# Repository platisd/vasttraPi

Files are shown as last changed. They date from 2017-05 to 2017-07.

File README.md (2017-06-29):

# VasttraPi
Your personal departures screen for Västtrafik buses. Currently it is hardcoded to look for buses going from Lindholmen to the center, but can be easily modified or extended. It uses a Python wrapper ([PyTrafik](https://github.com/axelniklasson/PyTrafik)), around the Västtrafik API by Axel Niklasson. Read more about the project and its background [here](https://platis.solutions/blog/2017/06/18/vasttrapi-my-personalized-vasttrafik-bus-stop/).

vasttrapi photo

## How to install
First, prepare your Raspberry Pi for connecting with your local wireless network and enable SSH. The following guide has been tested on **2017-03-02-raspbian-jessie** running on a **Raspberry Pi Zero W**.

* Set the correct timezone to your Pi
  * `sudo raspi-config`
  * Localisation Options
  * Change timezone
  * Europe
  * Stockholm
* Clone the vasttraPi repository
  * `git clone https://github.com/platisd/vasttraPi.git`
* Clone the PyTrafik repository
  * `git clone https://github.com/axelniklasson/PyTrafik.git`
* Install the PyTrafik Python3 module
  * `sudo pip3 install PyTrafik/`
* Make sure you have PySerial 3.3 or greater installed
  * sudo pip3 install pyserial --upgrade
* Create an api-config file with your [Västtrafik API tokens](https://developer.vasttrafik.se/portal/#/applications)
  * `nano vasttraPi/api-config`
  * Add your API tokens. The first line should be the (public) key and the second is the secret.
api config screenshot
* Make the Python3 GUI start right after boot
  * `nano /home/pi/.xsession`
  * Add: `python3 /home/pi/vasttraPi/departures.py`
  * To undo this, do not just empty the .xsession file, remove it completely.
* Sync, reboot and the departures screen should pop up
  * `sync`
  * `sudo reboot`

### Read-only & OverlayFS (Optional)
The Python3 script, which is configured to run on startup, is listening to the serial port for an "off" string in order to shutdown the Raspberry Pi. This is done in order to protect the SD card from being corrupted, even though this has rarely happened to me. That being said, if you do not want to bother with the extra USB-serial connection or feel like trying something new, an effective way of protecting the SD card is by using a read-only filesystem and OverlayFS. After a lot of search I found the great [instructions](http://wiki.psuter.ch/doku.php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) by Pascal Suter who provided a very useful [script](overlayRoot.sh) in order to achieve that.

* Copy the `overlayRoot.sh` script to `/sbin/`
  * `sudo cp /home/pi/vasttraPi/overlayRoot.sh /sbin/`
* Disable swap
  * `sudo dphys-swapfile swapoff`
  * `sudo dphys-swapfile uninstall`
  * `sudo update-rc.d dphys-swapfile remove`
* Once you have your partitions set up the way you want them edit the `/boot/cmdline.txt` to run the `overlayRoot.sh` script.
  * `nano /boot/cmdline.txt`
  * Append `init=/sbin/overlayRoot.sh` to the end of the existing file.
* After rebooting, any changes to the partitions will be non-persistent. If you want to undo this, simply restore the `/boot/cmdline.txt` to its original state.

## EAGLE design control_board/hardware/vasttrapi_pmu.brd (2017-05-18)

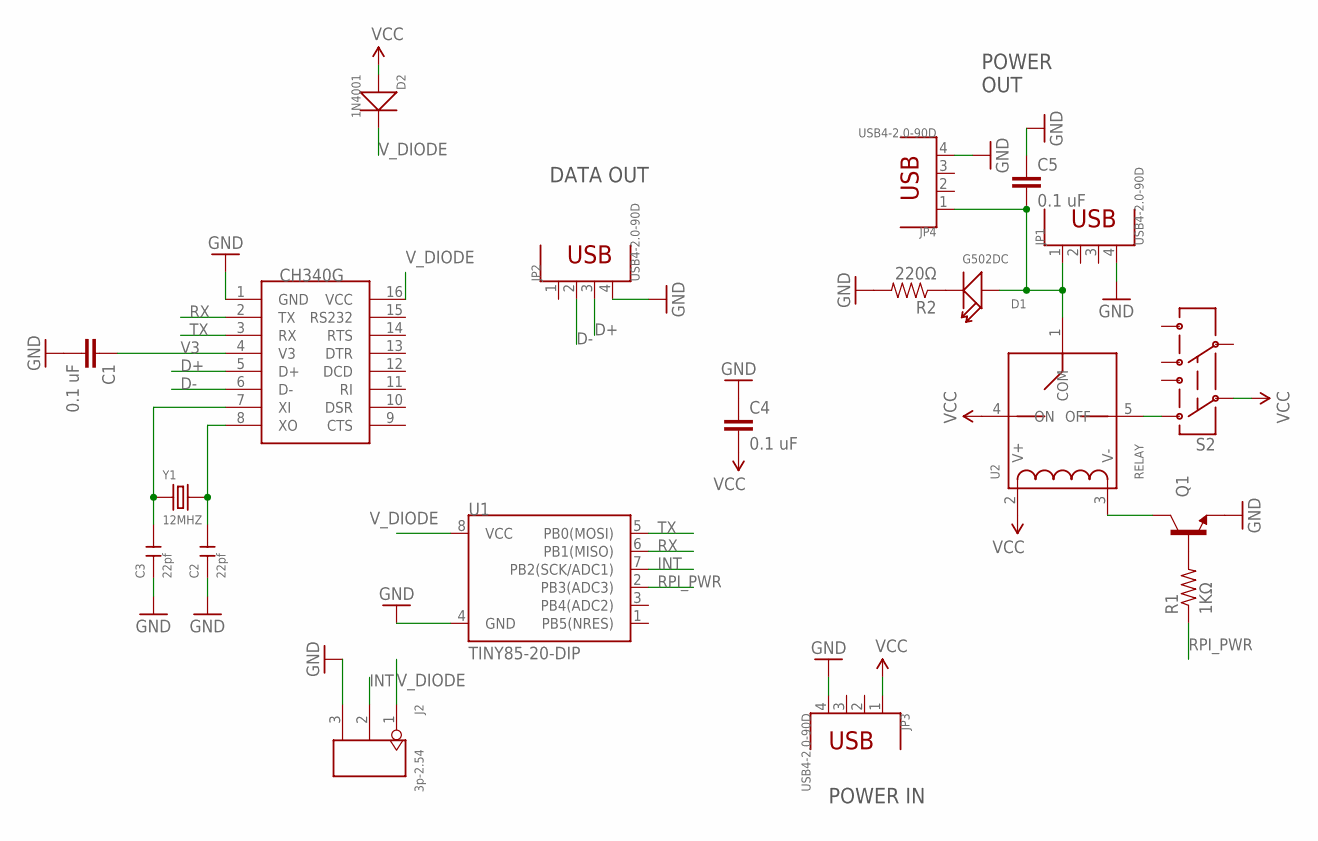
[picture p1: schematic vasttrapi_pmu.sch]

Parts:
C1, C4, C5: 0.1 uF; CAP-PTH-SMALL-KIT
C2, C3: 22pf; CERAMIC-2.54
D1: G502DC; LED2-2.54-D5.0MM
D2: 1N4001; DO-41
J2: 3p-2.54; H3-2.54
JP1, JP2, JP3, JP4: USB4-2.0-90D; USB4+2P-2.0-90D
Q1: TRANSISTOR_NPNBC547; TO-92-AMMO
R1: 1KΩ; AXIAL-0.4
R2: 220Ω; AXIAL-0.4
S2: SWITCH-DPDTOS; OS
U1: TINY85-20-DIP; DIP08
U2: RELAY
U$1: CH340G; SOIC16
Y1: 12MHZ; HC49US

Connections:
D+: JP2.3 (2), U$1.5 (D+)
D-: JP2.2 (3), U$1.6 (D-)
GND: C1.2, C2.1, C3.1, C4.1, C5.1, J2.3, JP1.4 (1), JP2.4 (1), JP3.4 (1), JP4.4 (1), Q1.3 (E), R2.P$2 (2), U1.4 (GND), U$1.1 (GND)
INT: J2.2, U1.7 (PB2(SCK/ADC1))
unnamed: Q1.2 (B), R1.P$2 (2)
unnamed: Q1.1 (C), U2.3 (V-)
unnamed: S2.1, U2.5 (OFF)
unnamed: C2.2, U$1.8 (XO), Y1.2
unnamed: C3.2, U$1.7 (XI), Y1.1
unnamed: D1.-, R2.P$1 (1)
RPI_PWR: R1.P$1 (1), U1.2 (PB3(ADC3))
RX: U1.6 (PB1(MISO)), U$1.2 (TX)
TX: U1.5 (PB0(MOSI)), U$1.3 (RX)
V3: C1.1, U$1.4 (V3)
VCC: C4.2, D2.1 (+), JP3.1 (5), S2.2, U2.2 (V+), U2.4 (ON)
VRPI: C5.2, D1.+, JP1.1 (5), JP4.1 (5), U2.1 (COM)
V_DIODE: D2.2 (-), J2.1, U1.8 (VCC), U$1.16 (VCC)

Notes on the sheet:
POWER IN
POWER OUT
DATA OUT

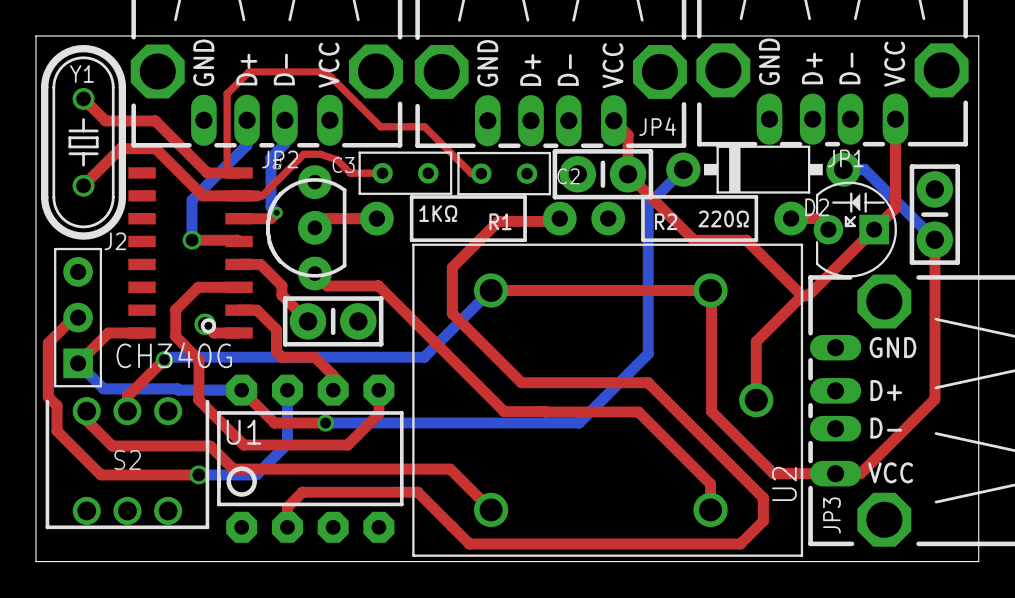
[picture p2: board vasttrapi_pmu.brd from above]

Board: 2 copper layers, 52.4 x 29.2 mm, 21 parts (0 on the bottom side), 17 nets.

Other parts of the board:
U$3: OSHWLOGO_BACK_0.2

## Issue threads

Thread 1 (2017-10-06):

Battery driven setup

larsbrinkhoff, 2017-10-06:
Hello,

I'd like to make something similar to this, except it supposed to be a wall-mounted clock.  I would like it to be powered off batteries instead.

Do you think there are low-power parts that can replace those you used?  I do need a 32-bit CPU running Linux in there, but it doesn't have to be quite as fast as an rPi.  I suppose the display draws most of the power anyway.  Monochrome without backlight is fine.

Thanks!

larsbrinkhoff, 2017-10-06:
E ink?  OLED?

platisd, 2017-10-06:
Hello Lars! Interesting inquiry!

So I assume you need something that is not expected to be updating or interacted with constantly and **should last about a month** (otherwise it is not fun, or is it?) on batteries. If you get a 10,000mAh powerbank you'd need your system's average consumption to be around... 15mA!

The single board Linux with the lowest consumption that I have used are the Raspberry Pi Zero and the Onion Omega. However they consume around one order of magnitude more, i.e. ~150mA. The worst part is that they lack a PMIC so there is little one can do to decrease that, by suspending to RAM.

My first suggestion would be to go for something that suspends to RAM in a really low power mode, but I could not find conclusive evidence of a specific board capable of that. The Beaglebone boards seem to support suspension to RAM but I could not find anything about the consumption during that state.

Therefore, due to the lack of a better and concrete solution, I would suggest a microcontroller periodically turning on the Linux machine.

Finally, I think an e-ink display is a must in any case, so to get the screen's consumption out of the equation.

larsbrinkhoff, 2017-10-06:
Thanks!

Looks like I have to forego the battery.  In my intended application, there should be a PDP-10 emulator running continuously.  And I don't want to change/charge batteries every week.

Though, I hear Tesla makes large batteries...

platisd, 2017-10-06:
I just saw what's this about. Cool! Unfortunately I do not think turning the computer on and off makes sense if you need to update it every minute. :sweat: I had in mind a way slower refresh rate.

larsbrinkhoff, 2017-10-06:
Every second, probably.

I think the processor could run somewhere around 100 MHz.  That might help.

platisd, 2017-10-06:
I believe the operating frequency is not the most important factor, but rather the ability of the processor to pull the system into a really low power mode when not updating the screen. This is very easy to do with microcontrollers, but unfortunately I do not think it is possible/easy with what you are trying.

OK, while writing just got an idea! What about this setup: An inexpensive and low consumption movement sensor, that triggers a microcontroller to power on the Linux system when someone is actually around? For movement sensing I have the following options in mind:
* [PIR sensor](https://www.aliexpress.com/item/Free-Shipping-5PCS-HC-SR501-Adjust-IR-Pyroelectric-Infrared-PIR-module-Motion-Sensor-Detector-Module/32667738141.html): Detects whatever is moving within the line-of-sight towards all directions.
Or if you are feeling adventurous...
* [Microwave radar](https://www.aliexpress.com/item/5-8GHZ-Microwave-Radar-Sensor-Module-Smart-Sensoring-Switch-6-9M-Home-Control/32602485648.html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): Should be able to detect movement through walls, so you can turn on the system even before someone walks in the room!
I have tried one of these radars out, was not super satisfied with their performance but generally did not spend enough time. I think they have a lot of potential.

From the user's perspective, the system is continuously on!

larsbrinkhoff, 2017-10-06:
Good thinking outside the box, I like it!  Also bonus points for involving a microcontroller. :-)

larsbrinkhoff, 2017-10-24:
I see now there are lamp sockets on the walls, so I probably won't need a battery.

Closed 2017-10-24.

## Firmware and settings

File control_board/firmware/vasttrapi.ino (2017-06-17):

/**
   Power Control board for the Raspberry Pi using an ATTinyx5 microcontroller.
   The Power Control board is using a relay to turn on and off the power to a Raspberry Pi.
   Additionally, they are connected via (software) UART for communication when the RPi is on.
   The microcontroller connected to a capacitive touch sensor which allows interaction with
   the external user that wants to turn the Raspberry Pi on and off.

   ==== STATES ====
   The microcontroller has the following states:
   - Sleep state where the microcontroller is in deep sleep and the power to the RPi is OFF.
   - Operation state where the microcontroller is triggering the relay to power on the RPi and
   can communication to it via UART.
   - Shutdown state where the microcontroller sends a UART instruction to the RPi to begin its
   shutdown sequence, in order to avoid damaging the SD card by abruptly turning the power off.

   ==== CURRENT FUNCTIONALITY ====
   Upon starting up, the microcontroller goes in deep sleep which can be interrupted by a HIGH
   signal coming from the capacitive sensor. This initiates a window of operation for the Raspberry Pi
   during which it will remain on. Every consecutive touch moves the end of this window further in the
   future, therefore, prolonging the period that the Raspberry Pi is functioning. In other words, on
   every touch, the operation gets extended for the specified amount of time.
*/

#include <avr/sleep.h>    // Sleep Modes
#include <avr/power.h>    // Power management

const unsigned short touchSensorPin = PB2;
const unsigned short rpiPwrPin = PB3;
const boolean powerOnState = HIGH; // The rpiPwrPin state that turns the power on to the RPi

volatile unsigned long timeToSleep = 0;
const unsigned long awakePeriod = 600000UL; // Time in milliseconds to remain awake on every new touch
const unsigned long shutdownTime = 12000; // Time in milliseconds to wait for the RPi to shutdown

enum PowerState {
  SLEEP,
  OPERATION,
  SHUTDOWN
};
PowerState currentState = SLEEP; // Begin in a deep sleep state

/**
   The change interrupt callback
*/
ISR (PCINT0_vect) {
  // We register a touch event only when the signal from the touchSensor is rising
  // Ignore touch events while in shutdown state
  if (currentState != SHUTDOWN && digitalRead(touchSensorPin) == HIGH) {
    timeToSleep = millis() + awakePeriod;
  }
}

/**
   Makes the microcontroller go to deep sleep until a change interrupt occurs
*/
void goToSleep() {
  set_sleep_mode(SLEEP_MODE_PWR_DOWN);
  ADCSRA = 0; // turn off ADC
  power_all_disable (); // power off ADC, Timer 0 and 1, serial interface
  sleep_enable();
  sleep_cpu(); // Sleep here and wait for the interrupt
  sleep_disable();
  power_all_enable(); // power everything back on
}

void turnRPiPowerOn() {
  digitalWrite(rpiPwrPin, powerOnState);
}

void turnRPiPowerOff() {
  digitalWrite(rpiPwrPin, !powerOnState);
}

/**
   UART command sent to the RPi to trigger its shutdown sequence
*/
void signalShutdown() {
  Serial.println("off");
  Serial.flush(); // Make sure that UART output has been transmitted before exiting this method
}

/**
   Wait for the RPi to shutdown properly. In the future more logic might be added here.
*/
void waitForRPiShutdown() {
  delay(shutdownTime);
}

void setup() {
  Serial.begin(9600); // The Universal ATtinyCore library by Spence Konde uses PB0 as TX and PB1 as RX
  pinMode(rpiPwrPin, OUTPUT);
  pinMode(touchSensorPin, INPUT);
  // Setup pin change interrupt for D2
  PCMSK |= bit (PCINT2); // want pin D2 (PB2)
  GIFR |= bit (PCIF); // clear any outstanding interrupts
  GIMSK |= bit (PCIE); // enable pin change interrupts
}

void loop() {
  switch (currentState) {
    case SLEEP:
      turnRPiPowerOff(); // Cut off the power to the RPi
      goToSleep(); // Deep sleep until a change interrupt at the specified pin is triggered
      currentState = OPERATION; // If we reach this, it means that a touch was registered so we should be operating
      break;
    case OPERATION:
      turnRPiPowerOn(); // Turn on the power to the RPi (if this is already on, it won't make any difference)
      if (millis() >= timeToSleep) { // Check if it is currently time to be asleep
        // If we were operational but it's time to sleep, then we should move to the shutdown state
        currentState = SHUTDOWN;
      }
      break;
    case SHUTDOWN:
      signalShutdown(); // Send a command via UART to the RPi which will make it initiate a shutdown sequence
      waitForRPiShutdown(); // Wait for the RPi to shutdown, while disabling interrupts so new touch events are not logged
      // Now that we should be certain that the RPi has shut down, we can put our state to SLEEP
      currentState = SLEEP;
      break;
    default:
      break;
  }
}

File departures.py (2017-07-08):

#!/usr/bin/python3
# -*- coding: utf-8 -*-
"""
VasttraPi - Your personal departures screen for Västtrafik buses

Running on: 2017-03-02-raspbian-jessie
To run the python GUI on startup appended python3 /home/pi/vasttraPi/departures.py in /home/pi/.xsession

PEP8 check with: pep8 --ignore=E501 departures.py
"""
import pytrafik.client
import json
from socket import AF_INET, SOCK_DGRAM
import socket
import struct
import time
import threading
from datetime import datetime
from collections import defaultdict
import tkinter as tk
import os
import sys
import getpass
import serial

# Change working directory to the one that the file is residing in
abspath = os.path.abspath(__file__)
dname = os.path.dirname(abspath)
os.chdir(dname)

onPi = getpass.getuser() == "pi"  # To determine whether we are on the raspberry pi

apiKey = None
apiSecret = None
pathToConfig = "api-config"  # Path to a non-version controlled file that stores API tokens
vasttrafik = None  # The variable to hold the socket connection to the public API

mainThread = threading.current_thread()

LINDHOLMEN_ID = "9021014004490000"
TEKNIKGATAN_ID = "9021014006675000"
stations = {"Lindholmen": LINDHOLMEN_ID, "Teknikgatan": TEKNIKGATAN_ID}
sideColumnMinSize = 100
departureFontSize = 40
destinationFontSize = int(departureFontSize / 2) if onPi else departureFontSize
headerFontSize = 25
subHeaderFontSize = 20
guiRefreshRate = 15  # How often to check the Vasttrafik API for new departures (in seconds)
serialPollRate = 3  # How often to check for incoming serial data (in seconds)
maxFutureDepartureTime = 120  # The maximum amount of time (in minutes) left for a departure that is displayed
timeoutNTP = 1.0  # How much to wait for the NTP server's response in seconds
tokenTimeout = 3600  # How much time your token is valid (default is 3600 seconds, i.e. 1 hour)

# Configure the serial connection attributes without initializing it
powerControlSerial = serial.Serial()
powerControlSerial.port = "/dev/ttyUSB0"
powerControlSerial.baudrate = 9600
powerControlSerial.bytesize = 8
powerControlSerial.parity = "N"
powerControlSerial.stopbits = 1
powerControlSerial.timeout = 0.1  # The amount of seconds to wait for incoming UART stream


def disableScreenblanking():
    os.system("export DISPLAY=:0.0 && xset s off && xset s noblank && xset -dpms")


# Fetches the time from NTP server. Source: http://blog.mattcrampton.com/post/88291892461/query-an-ntp-server-from-python
def getNTPTime(host="pool.ntp.org"):
    port = 123
    buf = 1024
    address = (host, port)
    msg = '\x1b' + 47 * '\0'

    # Reference time (in seconds since 1900-01-01 00:00:00)
    TIME1970 = 2208988800  # 1970-01-01 00:00:00

    # connect to server
    client = socket.socket(AF_INET, SOCK_DGRAM)
    client.settimeout(timeoutNTP)  # Do not wait too much to receive a response from the NTP server
    try:
        client.sendto(bytes(msg, "UTF-8"), address)
        msg, address = client.recvfrom(buf)
        t = struct.unpack("!12I", msg)[10]
        t -= TIME1970
    except:
        print ("WARNING: Could not fetch time from NTP server! Using system time instead.")
        t = time.time()  # Fall back to the system time when no response from ntp server

    d = time.strptime(time.ctime(t), "%a %b %d %H:%M:%S %Y")
    return (time.strftime("%Y-%m-%d", d), time.strftime("%H:%M", d))


# Fetches the consumer and secret key from configuration file (not version controlled).
# The first line is the key and the second is the secret.
def initAPIkeys():
    f = open(pathToConfig)
    global apiKey, apiSecret
    apiKey = f.readline().replace('\n', "")
    apiSecret = f.readline().replace('\n', "")
    f.close()


# Initializes the connection to the Vasttrafik server
def initializeConnection():
    try:
        global vasttrafik
        vasttrafik = pytrafik.client.Client("json", apiKey, apiSecret)
    except Exception as e:
        print ("Authentication failure, exiting!")
        sys.exit(1)
    # We need to reinitialize the token after it's timed out
    if mainThread.is_alive():
        threading.Timer(tokenTimeout, initializeConnection).start()


# Get the next trips as a list of busline numbers and minutes to leave for the next two trips
def getNextTrips():
    # Get the current time and date from an NTP server as the host might not have an RTC
    (currentDate, currentTime) = getNTPTime()
    trips = defaultdict(list)  # A dictionary of lists, holding a list of departures for each bus
    for stationName, stationID in stations.items():
        # Get the departures for each station we are interested in
        try:
            departures = vasttrafik.get_departures(stationID, date=currentDate, time=currentTime)
        except Exception as e:
            print ("Connection failure for station %s" % stationName)
            departures = []  # If something went wrong, empty the departures list so we don't try to iterate through them
        for departure in departures:
            if departure['track'] < 'C':  # We only care for buses going towards the center for now
                try:
                    # Sometimes rtTime is not returned, so fall back to normal time instead
                    departureTime = departure['rtTime'] if 'rtTime' in departure else departure['time']
                    trips[(departure['sname'], departure['direction'])].append(departureTime)
                    #print ("Bus %s leaves towards %s at %s" % (departure['sname'], departure['direction'], departure['rtTime']))
                except Exception as e:
                    print ("Error while parsing server response")
    #print (sorted(trips.items()))
    nextTrips = []
    for (busLine, destination), departureTimes in trips.items():
            remainingDepartures = 2  # The number of departures that we care to show
            for departureTime in departureTimes:
                remainingDepartures -= 1
                if remainingDepartures < 0:
                    break
                minutesToLeave = ((datetime.strptime(departureTime, "%H:%M") - datetime.strptime(currentTime, "%H:%M")).total_seconds() / 60)
                # If a bus leaves the next day, the above result will be a negative number, therefore we need to completement it
                # with the amount of minutes in a day (1440)
                if minutesToLeave < 0:  # meaning that the next departure time is on the next day
                    MINUTES_IN_DAY = 1440
                    minutesToLeave += MINUTES_IN_DAY
                #print ("Bus %s, leaves in %d" % (busLine, minutesToLeave))
                nextTrips.append((busLine, destination, minutesToLeave))
    return nextTrips
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

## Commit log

2017-04-09 Work in progress, added top frames and next trips as a list of tuples
2017-04-09 Changing the current directory so it can be called from different folders
2017-04-09 Row frames initial implementation
2017-04-09 pep8 formatting fixes
    Ran with: pep8 --ignore=E501 departures.py
    [departures.py]
2017-04-22 Firmware for the control board MCU
2017-04-22 Rev.1 power control board schematics
    [vasttrapi_pmu.brd, vasttrapi_pmu.sch]
2017-04-23 Shutting down the Pi upon receiving UART instruction
2017-04-24 Polling serial in a separate thread
    In order to decouple it from the gui update and increase the polling rate
2017-05-18 hw rev.2
    Added diode before the MCU, serial-to-usb chip and sensor
    [vasttrapi_pmu.brd, vasttrapi_pmu.sch]
2017-05-18 small fix to switch footprint
    [vasttrapi_pmu.brd, vasttrapi_pmu.sch]
2017-05-18 led position fix
    [vasttrapi_pmu.brd]

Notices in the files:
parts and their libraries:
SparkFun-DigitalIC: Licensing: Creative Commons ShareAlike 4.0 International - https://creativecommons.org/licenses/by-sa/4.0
